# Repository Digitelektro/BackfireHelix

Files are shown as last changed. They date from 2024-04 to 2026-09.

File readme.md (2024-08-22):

# Backfire helix antenna for L and S band weather satellites

This feed is suitable for deep prime focus dishes with an f/D ratio ranging from 0.3 to 0.5. Considering the mirroring effect the dish has on signal polarization, this feed is designed as LHCP; with the dish flipping it, making reception of RHCP satellite signals suitable.

Please read carefully the notes below before you start building it yourself!

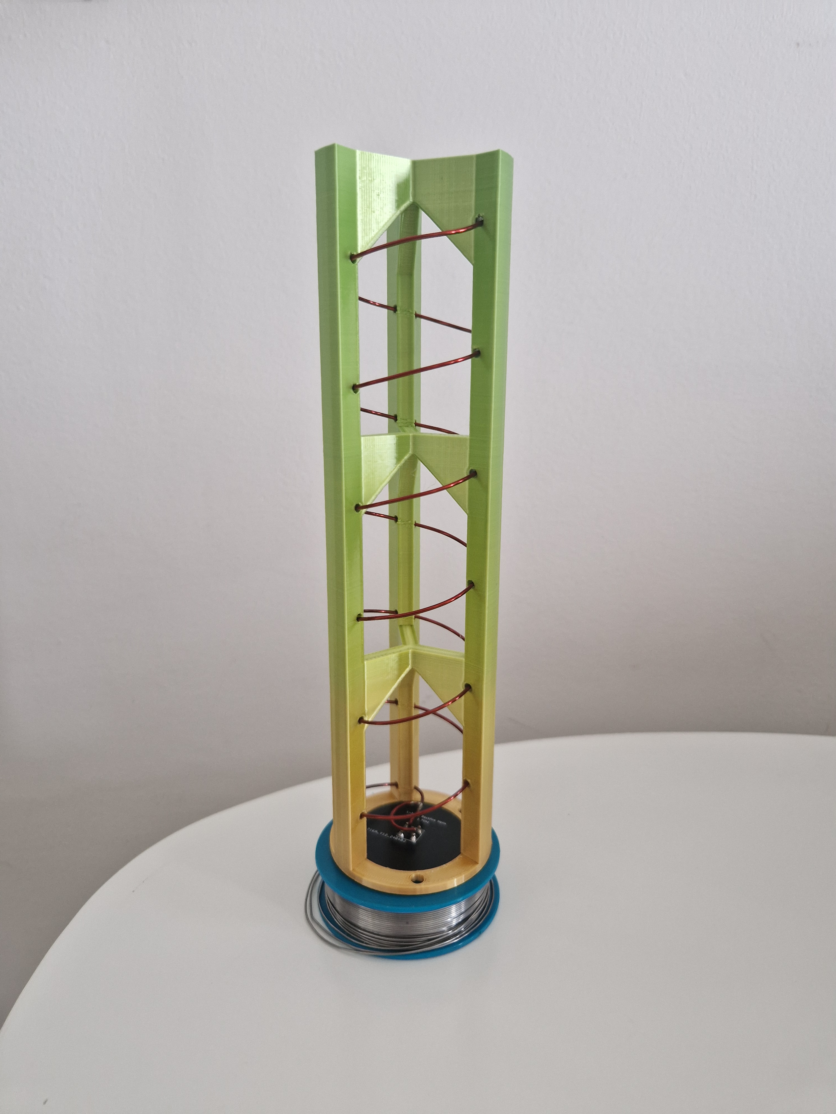
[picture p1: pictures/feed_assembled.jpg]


## Background

The original "WiFi" grid and the Nooelec grid dishes come with linear polarized feeds. However, L-band polar-orbiting weather satellites transmit circularly polarized signals.  This polarization mismatch results in a 3 dB loss when using linear feeds. I wanted to design a circularly polarized feed to address this issue. After reading a lot about antenna feeds, I selected this particular design for its favorable characteristics and ease of construction. After simulation and real-world tests, it proved to work great on my setup; in contrast with the Nooelec's linear feed, I got about 3 dB better SNR.

This Backfire helix design is based on Hisamatsu Nakano, Junji Yamauchi, Hiroaki Mimaki: Backfire Radiation from a Monofilar Helix with a Small Ground Plane, IEEE TRANSACTIONS ON ANTENNAS AND PROPAGATION, VOL. 36, NO. 10, OCTOBER 1988

Another good resource is [W1Ghz antenna book](http://www.w1ghz.org/antbook/contents.htm).

The scaffold design is based on [Derek's](https://twitter.com/dereksgc) helix design.

## Important notes

- If you have a grid dish like a Wf-fi grid dish or Nooelec grid dish, it must be covered with a fine mesh wire, since these dishes is made for linear polarized signals.

- You'll find the PCB Gerber files for the backplate in the Gerber folder. If you decide to build the PCB, make sure it snugly fits into the antenna scaffold; otherwise, adjust the hole size with sandpaper or a sharp knife. The SMA connector I've used is [from Mouser](https://eu.mouser.com/ProductDetail/712-CONSMA001-C-G), but similar should work too.

- The size of the back plate plays an important role in the feed pattern! Using a random-sized plate will not work! Additionally, anything metallic around the backplate can negatively impact feed performance; therefore, it’s advisable to support the feed from underneath. Anything smaller than the backplate shouldn't alter feed characteristics. I haven't tested the metallic feed holder yet as I'm using a 3D-printed one and a PVC tube.

- The feed’s impedance is approximately 150 ohms. To achieve optimal performance, it needs to be tuned to 50 ohms to avoid an impedance mismatch and signal loss. Adding a tuning strip to the feed can help achieve a good VSWR of around 1.2. For precise matching, utilize a Vector Network Analyzer (VNA) to determine the correct strip or wire size—keep in mind that not any size will suffice. Antenna matching requires experimentation, adjusting wire distance from the backplate, tuning element length, and distance from the ground plate and center. See pictures for a reference.

- You must use the shortest cable possible for connecting the feed to the LNA, as cable length increases the received signal attenuation. I suggest you make your replacement antenna feed holder and fit an LNA right below the backplate if the one which came with the dish doesn't allow it. If that's not possible, use a good-quality low-loss coax.

- Nooelec's feed holder on their dish (like I have) is specifically designed for it. If you have a different dish, you must design a custom feed holder! The focal point of my helix differs from the original dipole feed. You must experiment to find the correct spot.

- While a regular helix functions as a wideband antenna, the radiation pattern of a backfire helix is significantly influenced by the frequency. Specifically, this design performs exceptionally well in the frequency range of 1650 to 1800 MHz.

- Holes on the scaffold are made for ~1.2mm wire.

- Holes for holding together the feed holder and the feed are for M3 bolts. You can use cable tiers too.

## Tuning pictures

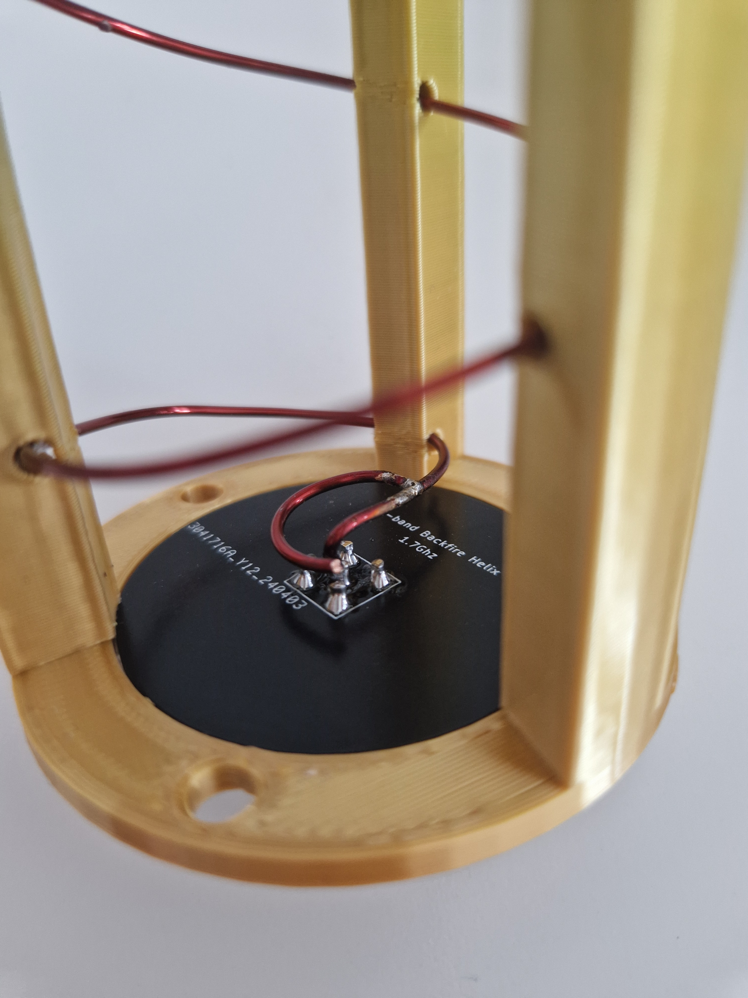
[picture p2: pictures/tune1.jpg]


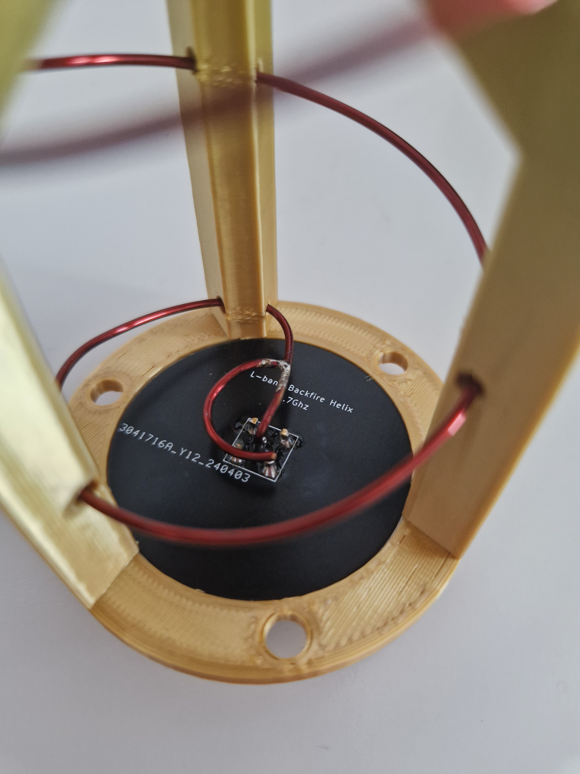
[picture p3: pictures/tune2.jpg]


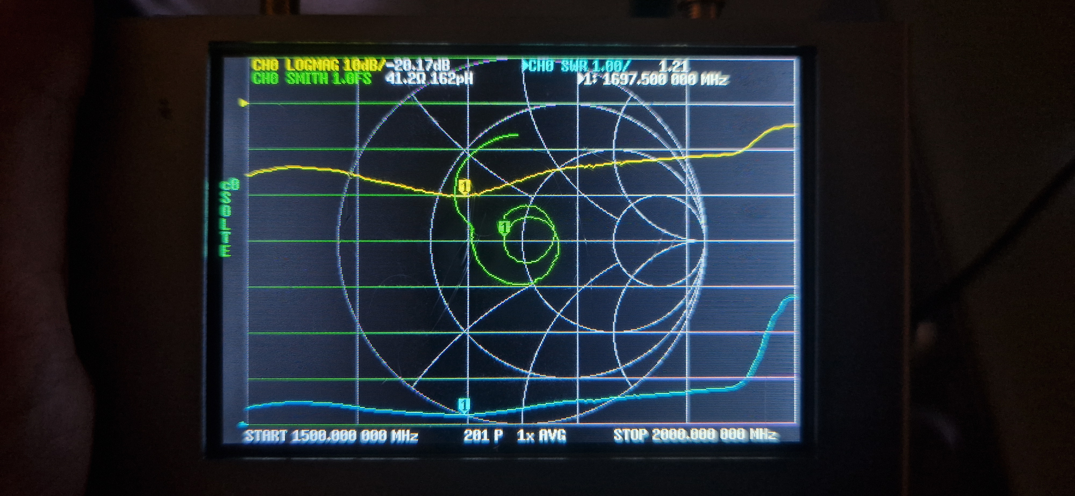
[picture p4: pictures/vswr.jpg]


## Simulation result

### NEC4 simulation with NEC2 engine 

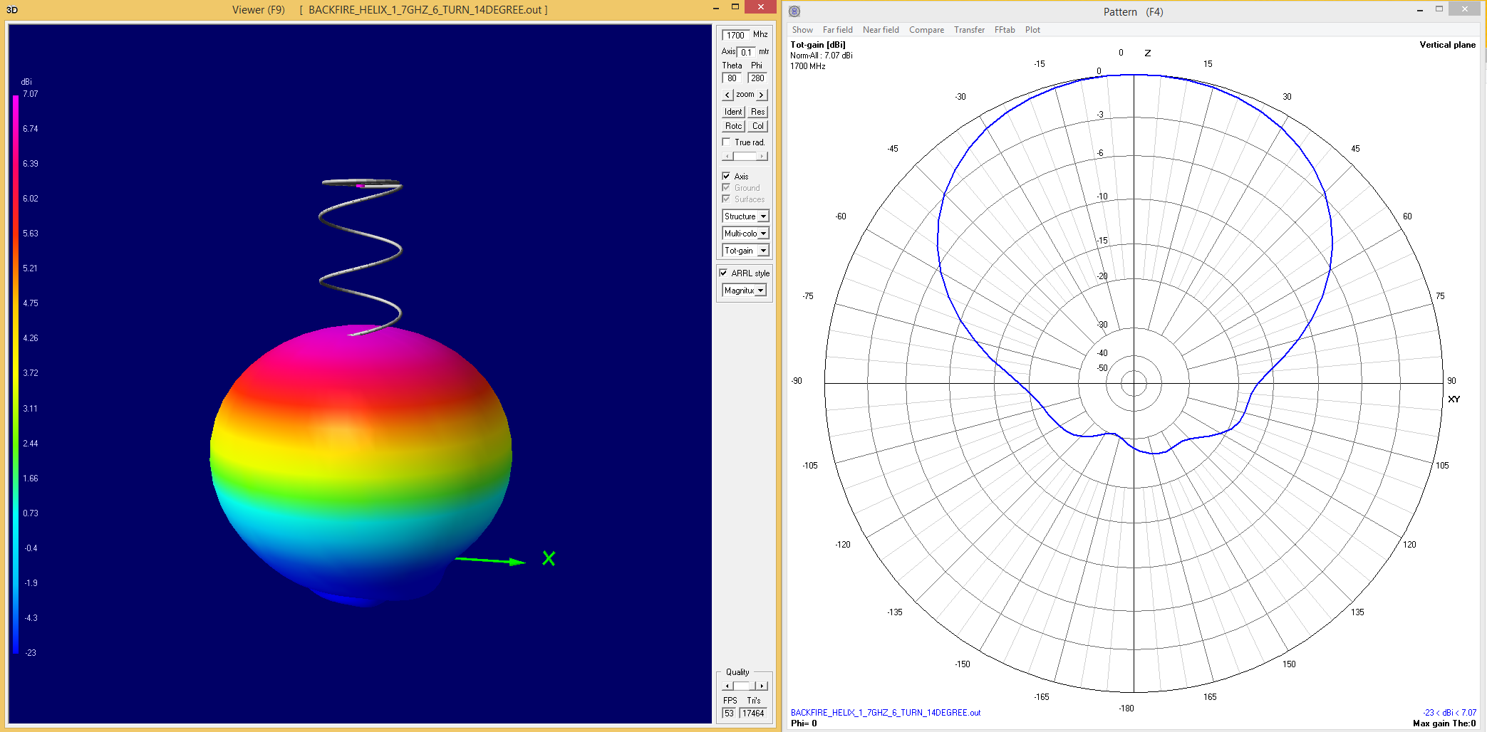
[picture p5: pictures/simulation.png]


### Dish efficiency using W1GHZ's feedpattern calculator

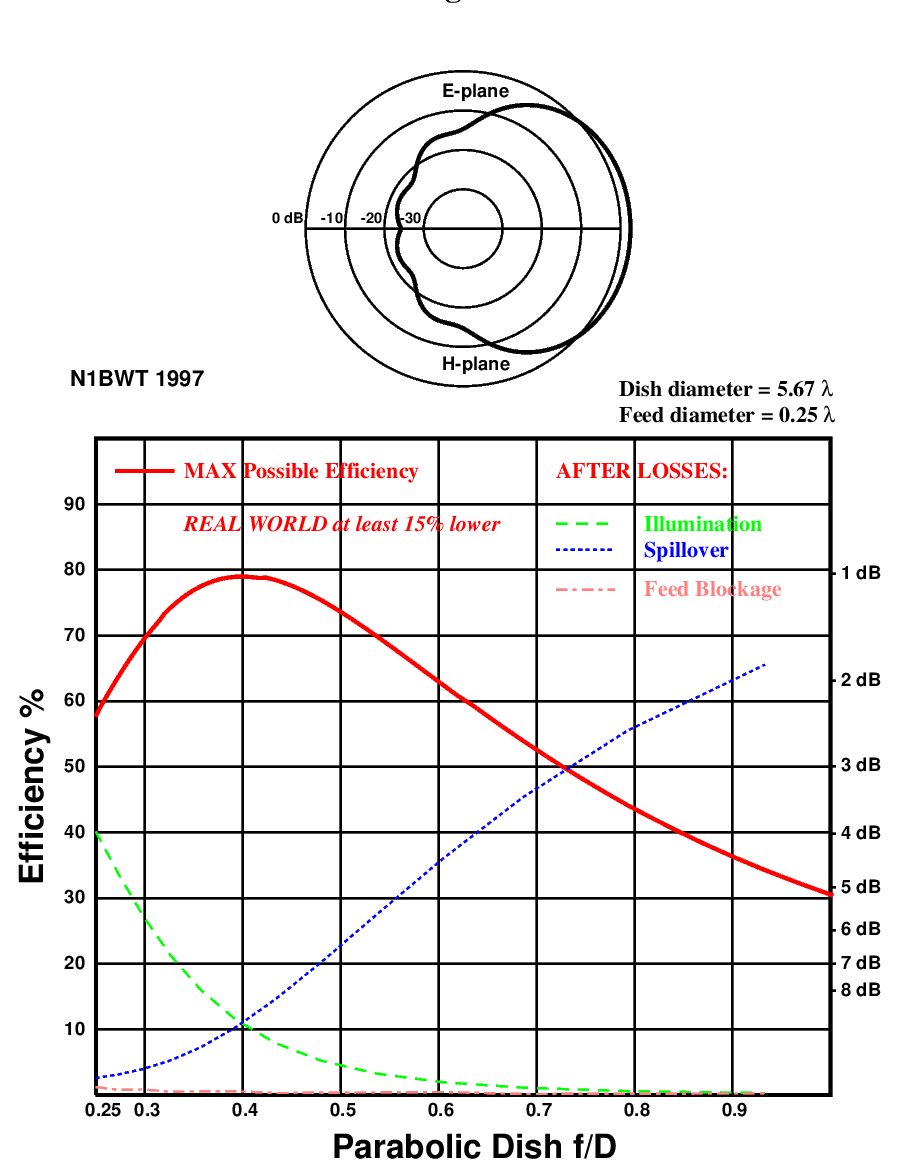
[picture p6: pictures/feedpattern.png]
Dish efficiency


## Future

An LNA circuit could be made on the back plate. Coming soon!

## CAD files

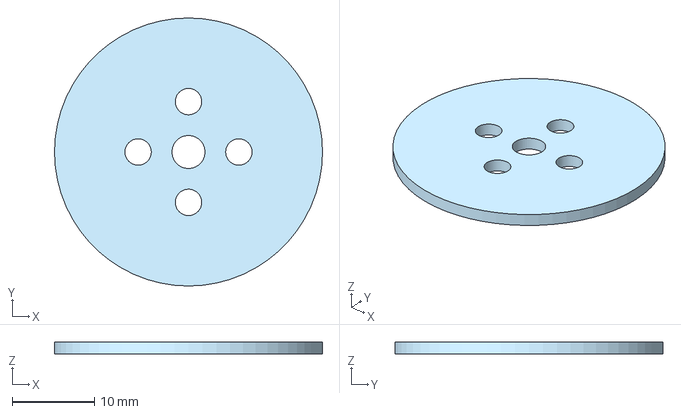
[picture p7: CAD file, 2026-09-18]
step/2.23GHz_reflector_32.5mm.step
32.5 x 32.5 x 1.50 mm

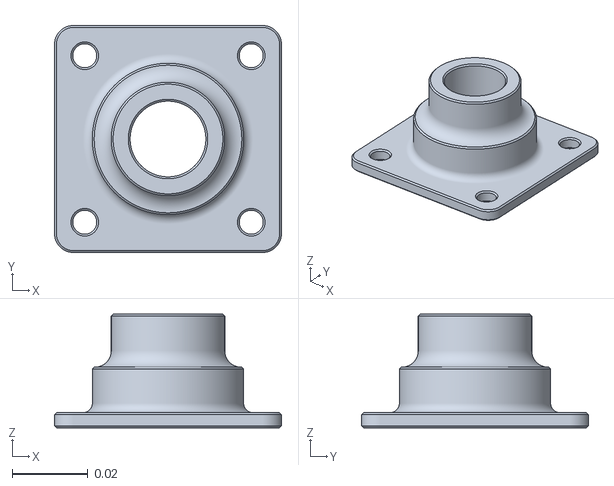
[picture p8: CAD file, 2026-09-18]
stl/ubiquiti_nanobridge_m5_25dBi_20mm_feedarm_adapter.stl
0.06 x 0.06 x 0.03

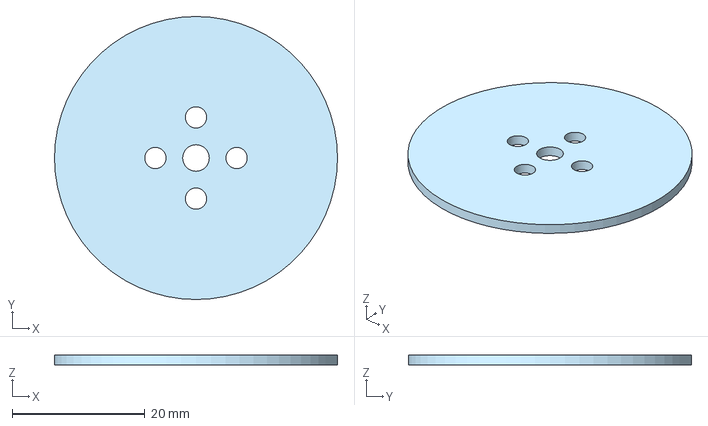
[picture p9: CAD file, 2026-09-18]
step/1.7GHz_reflector_42.6mm.step
42.6 x 42.6 x 1.50 mm

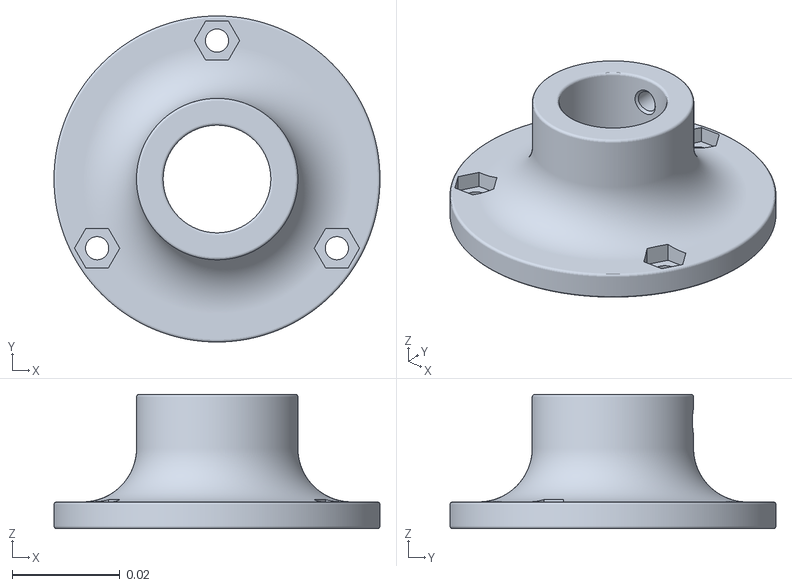
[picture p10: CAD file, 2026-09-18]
stl/backfire_helix_20mm_feedarm_adapter.stl
0.0606 x 0.0606 x 0.025

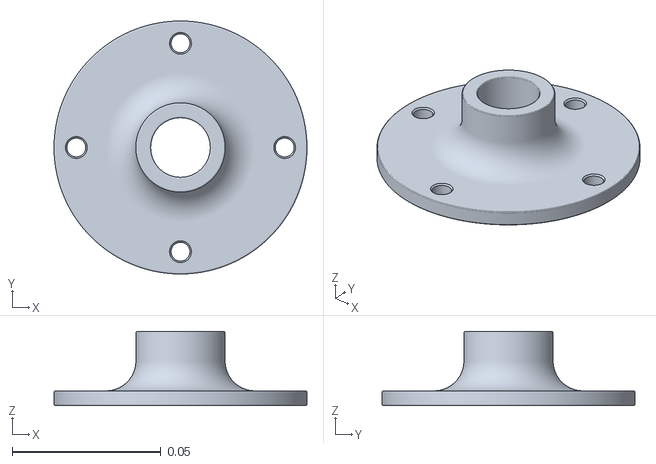
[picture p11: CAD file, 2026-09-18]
stl/aliexpress_60cm_dish_20mm_feedarm_adapter.stl
0.085 x 0.085 x 0.025

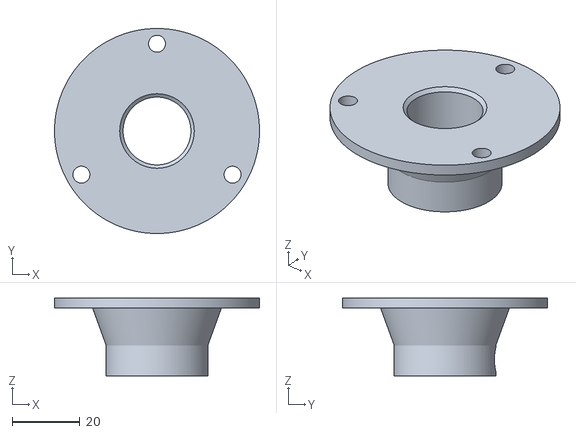
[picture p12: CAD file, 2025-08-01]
stl/backfire_helix_compact_adapter_for_discovery_dish.STL
60.5 x 60.5 x 23.0

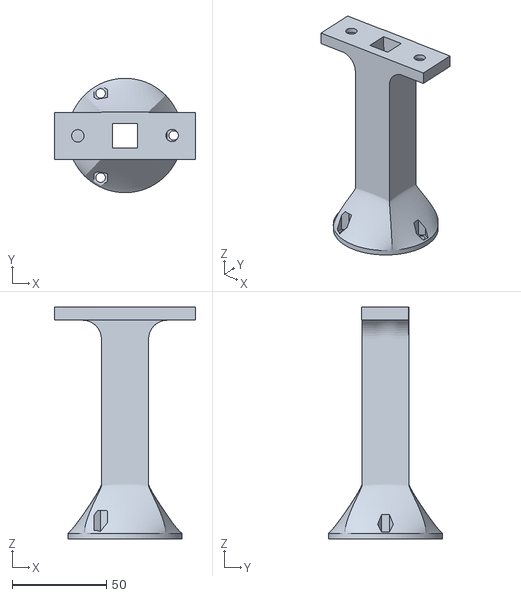
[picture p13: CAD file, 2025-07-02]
stl/backfire_helix_arm_for_60x40_grid_dish.STL
75.0 x 60.6 x 123.0

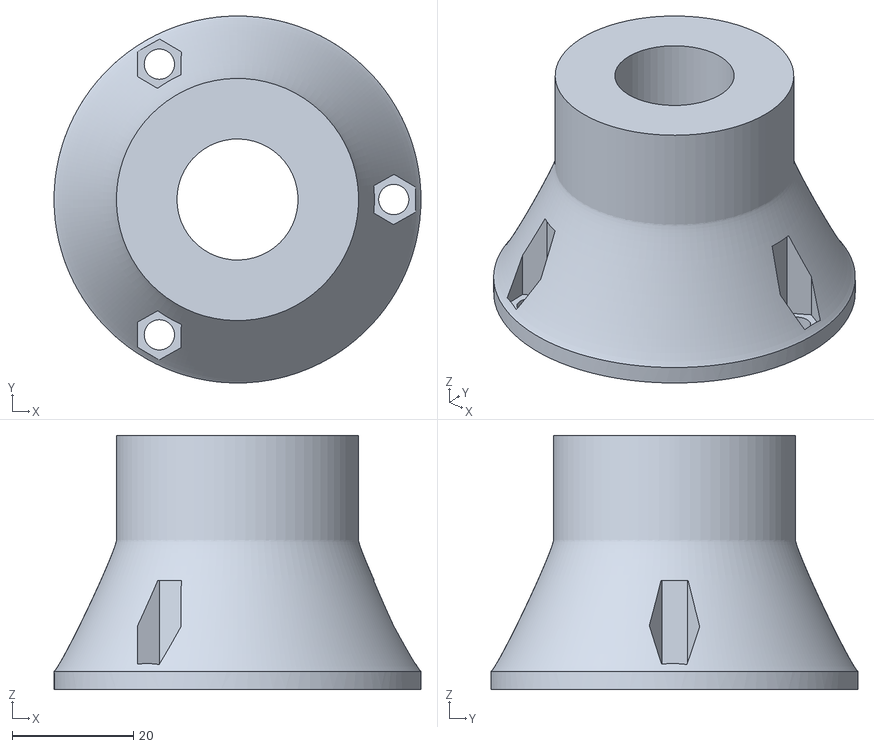
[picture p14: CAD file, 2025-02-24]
stl/backfire_helix_adapter_for_discovery_dish.STL
60.6 x 60.6 x 42.0

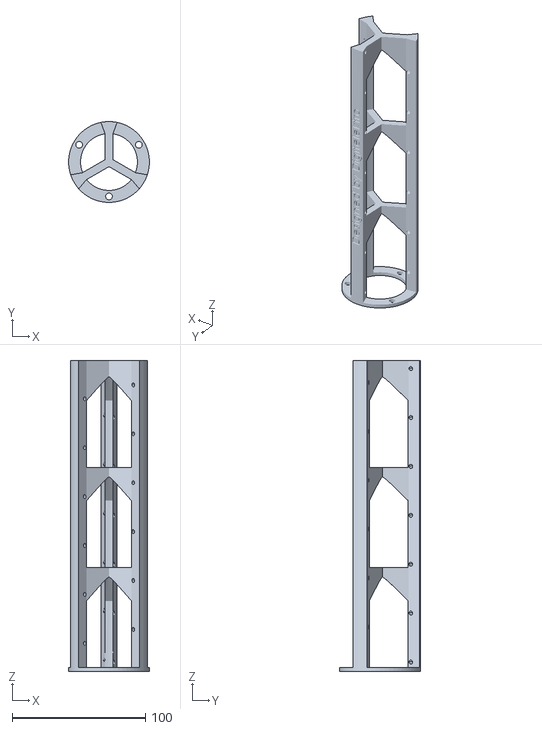
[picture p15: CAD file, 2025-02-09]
stl/lhcp_backfire_helix_1_7Ghz.STL
60.6 x 60.6 x 233.0

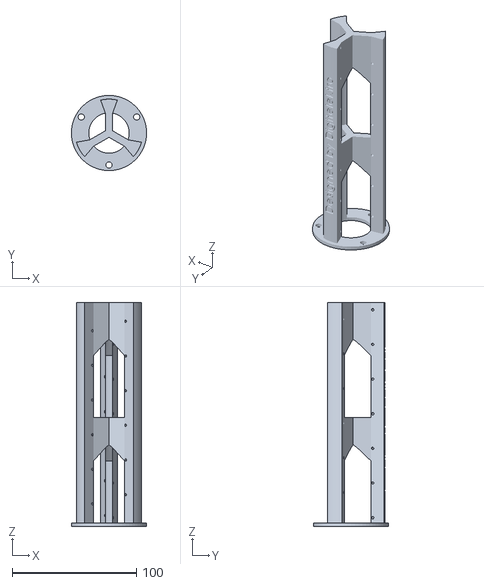
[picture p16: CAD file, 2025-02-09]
stl/lhcp_backfire_helix_2.23Ghz.STL
60.6 x 60.5 x 180.6

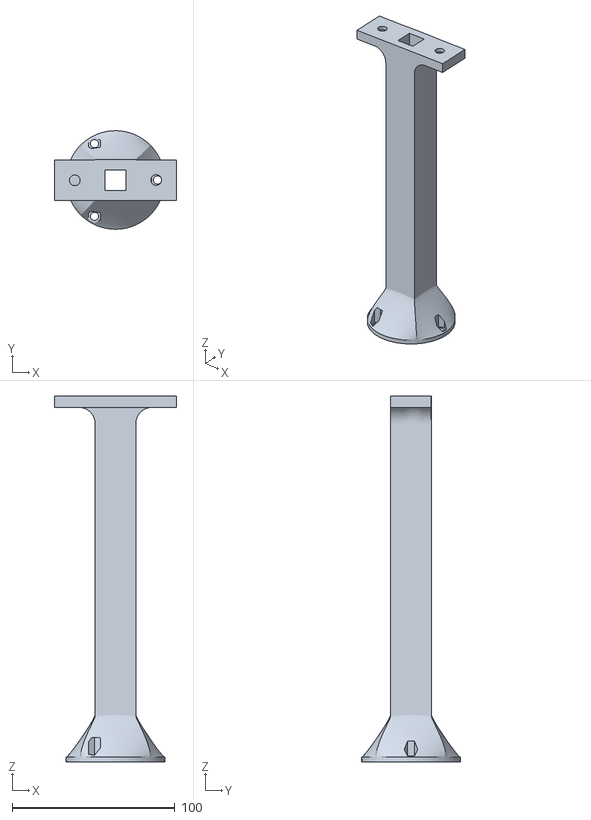
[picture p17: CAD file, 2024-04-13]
stl/backfire_helix_arm_for_100x60_grid_dish.STL.STL
75.0 x 60.6 x 225.0

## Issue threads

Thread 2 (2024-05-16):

2.23 GHz Helix STL file

lucapandolfini, 2024-05-16:
Hello, really nice design, thank you.
I was wondering how the 2.23GHz helical feed is meant to be installed. I have seen in the STL file that the base of the helix has no screw holes and its diameter is different from that of the holding arm (which on the contrary fits perfectly the 1.7GHz feed). Do you have any experience/suggestion about how to adapt / modify the arm for this feed? Thank you

Digitelektro, 2024-05-17:
Hi! Thank you!
Hmm, I was more focusing on the L-band version, I will update the design and add the screw holes over this weekend!
Also somebody reported that the feed holder arm should be longer for S-band. While it works with the current feed holder, a longer one could contribute to the SNR a bit. The problem is I cannot print longer feed holder, I reached my printer capabilities.

Digitelektro, 2024-05-17:
stl file is updated!

lucapandolfini, 2024-05-17:
Would it be difficult/time consuming to design an arm that fits the original 2.23 GHz feed (with the same diameter)? I am asking this because I already 3d-printed that... :( thanks a lot!

Digitelektro, 2024-05-17:
[backfire_helix_holder_for_S_band.zip](https://github.com/Digitelektro/BackfireHelix/files/15347912/backfire_helix_holder_for_S_band.zip)
I didn't tested it, I hope size is good. Good luck!

lucapandolfini, 2024-05-17:
Thanks a lot, awesome!

Closed 2024-05-17.

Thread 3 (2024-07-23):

Metallic mesh mod?

lucapandolfini, 2024-07-23:
Hello, forgive the naive question, but I noticed in one picture of yours that you installed a metallic mesh net on the dish together with the helical feed.
Indeed it makes sense since the circularly polarised signal is not reflected in the vertical component of the dish, that has very few, sparse horizontal lines.
In my case, without this modification, a properly tuned 1.7GHz helical feed performs *worse* than the original wifi feed (with the apical reflector reversed).
Is it something to be expected?

Digitelektro, 2024-07-24:
Hi! Good question! I think it is something to be expected. I might need to update the readme with this info. Since I covered with my dish long before this backfire helix feed was created, I didn't even think about this.
On which satellite do you test the feed?

lucapandolfini, 2024-07-24:
I tested it on the Elektro-L2 GGAK-E signal. I did not find any info regarding whether it is indeed circularly polarized or not, though.

Digitelektro, 2024-07-24:
Elektro-L2 GGAK is circular polarized. Can you cover you dish with mesh and test it again please?

lucapandolfini, 2024-07-24:
Hi thanks for the reply!

Unfortunately at the moment I do not have access to the dish, I will
make some tests and send my results in a couple of weeks.
Which mesh do you use?

 On Wed, 2024-07-24 at 03:00 -0700, Digitelektro wrote:
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

--
Luca Pandolfini
Researcher
-------------------------------------
Istituto Italiano di Tecnologia - IIT
Center for Human Technologies (CHT)
Tower B, Erzelli Science Park 
Via Enrico Melen 83
16152 Genova, Italy

Digitelektro, 2024-07-24:
Okay, no hurry!
The mesh I use is what I found in a local hardware store, it is a ~5mm spacing mesh, nothing special.

lucapandolfini, 2024-08-18:
Ok, after some tests, I can confirm that the helix works better than the linear feed after installing a 5mm metallic mesh. I think it might be worth mentioning it in the readme. Thank you!

Digitelektro, 2024-08-22:
Thanks for testing it! I updated the readme.

Closed 2024-08-18.

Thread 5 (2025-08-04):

Add openscad source and simualtion file

dl3jop, 2025-08-04:
Hey,
thank you for the cool design.

Would you mind sharing the openscad and simulation source files to play around with?

Digitelektro, 2025-08-04:
Hi,
It is not created using openscad, but a cad software. I don't intend to share that.
I uploaded the nec files here(I renamed them to txt, otherwise github didn't accept them)

[backfire_helix_2230Mhz.txt](https://github.com/user-attachments/files/21576257/backfire_helix_2230Mhz.txt)
[backfire_helix_1_7Ghz_6_turn_14degree.txt](https://github.com/user-attachments/files/21576258/backfire_helix_1_7Ghz_6_turn_14degree.txt)

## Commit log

2024-04-13 Files added
    [backfire_helix_arm_for_grid_dish.STL, lhcp_backfire_helix_1_7Ghz.STL, lhcp_backfire_helix_2.23Ghz.STL]
2024-05-17 S-band helix screw holes added
    [lhcp_backfire_helix_2.23Ghz.STL]
2024-08-22 Wire mesh included in the readme
2025-02-09 Added text to scaffolds
    [lhcp_backfire_helix_1_7Ghz.STL, lhcp_backfire_helix_2.23Ghz.STL]
2025-02-24 Adapter for Discovery dish added
    [backfire_helix_adapter_for_discovery_dish.STL]
2025-07-02 Added feed holder for 60x40cm grid dish
    [backfire_helix_arm_for_100x60_grid_dish.STL.STL, backfire_helix_arm_for_60x40_grid_dish.STL]
2025-08-01 Added a compact variant of the DD adapter.
    [backfire_helix_compact_adapter_for_discovery_dish.STL]
